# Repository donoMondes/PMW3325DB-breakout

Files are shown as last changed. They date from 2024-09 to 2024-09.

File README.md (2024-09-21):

# PMW3325DB-TWV1 breakout board

This repository contains PCB design files for a breakout board for the PMW3325DB optical mouse sensor.

The board doesn't do any level shifting so it only works with 3.3V logic.

The dimensions of the board are 45x25mm and the mounting holes are for M2 screws with meta inserts.

The files in the [fabrication](fabrication) folder can be used to order this board from JLCPCB with SMT assembly. The board you get includes everything except the actual sensor. If some of the specific components are out of stock, try to find an equivalent with the same package and parameters.

If the volatage regulator **TCR2EF19** is out of stock, you can replace it by using the following configuration :

| **Reference** | **Part Name** | **JLCPCB P/N** |**Description**|
|--- |--- |--- |---|
| U2 | TLV74318PDBVR | C15849 | Voltage regulator with Vout = 1.8v  |
| C1 | C15849 CL10A105KB8NNNC| C485152 | Capacitor of 1uF  |

**Warning** Don't forget to turn the TLV74318PDBVR when making the position during the PCBA process

The sensor chip should be soldered on the top side (the side where all the other components are). The dot marks pin 1. The optic goes on the bottom side.

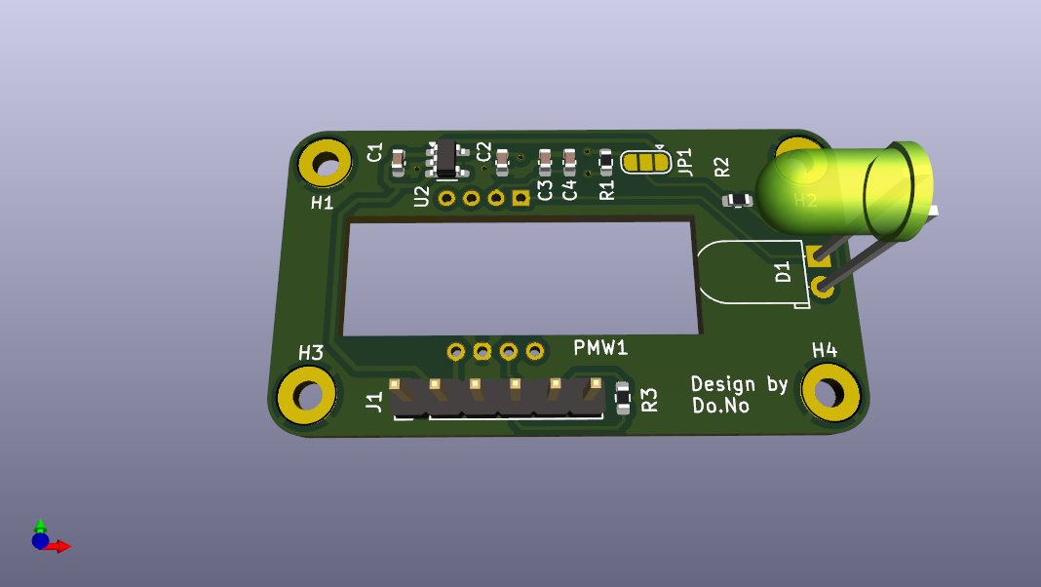
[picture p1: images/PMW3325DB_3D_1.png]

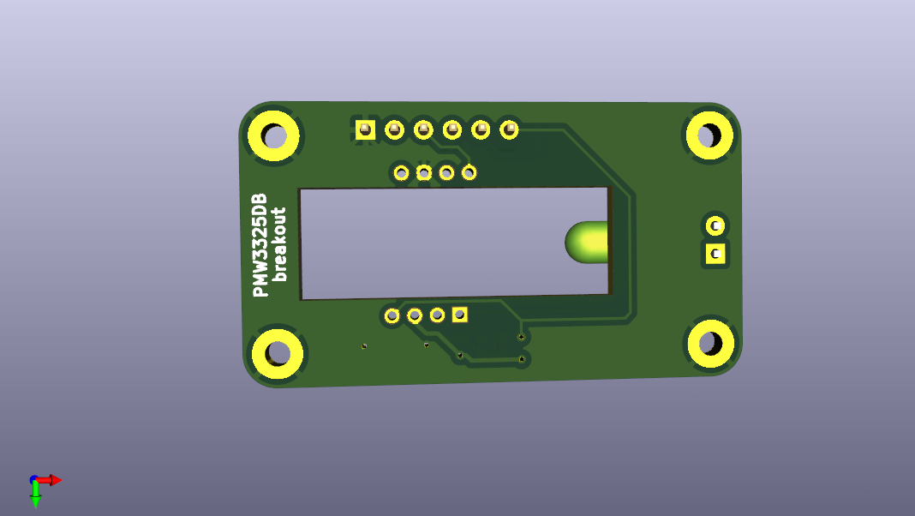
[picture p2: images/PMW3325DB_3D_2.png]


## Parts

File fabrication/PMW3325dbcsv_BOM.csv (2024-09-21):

Reference | Value | Datasheet | Footprint | Qty | DNP
C1 | 0.1u | ~ | Capacitor_SMD:C_0603_1608Metric | 1
C2 | 1u | ~ | Capacitor_SMD:C_0603_1608Metric | 1
C3 | 4.7u | ~ | Capacitor_SMD:C_0603_1608Metric | 1
C4 | 100nf | ~ | Capacitor_SMD:C_0603_1608Metric | 1
D1 | IR204A | http://www.everlight.com/file/ProductFile/IR204-A.pdf | LED_THT:LED_D5.0mm_Horizontal_O1.27mm_Z15.0mm | 1
J1 | Conn_01x06 | ~ | Connector _PINHeader:PinHeader_1x06_P2.54mm_Vertical | 1
PMW1 | PMW3325DB-TWV1 |  | adns 5050:PMW3325DB-TWV1 | 1
R1 | 10k | ~ | Resistor_SMD:R_0603_1608Metric | 1
R2 | 82 | ~ | Resistor_SMD:R_0603_1608Metric | 1
R3 | 3.3k | ~ | Resistor_SMD:R_0603_1608Metric | 1
U2 | TCR2EF19 |  | Package_TO_SOT_SMD:SOT-23-5 | 1

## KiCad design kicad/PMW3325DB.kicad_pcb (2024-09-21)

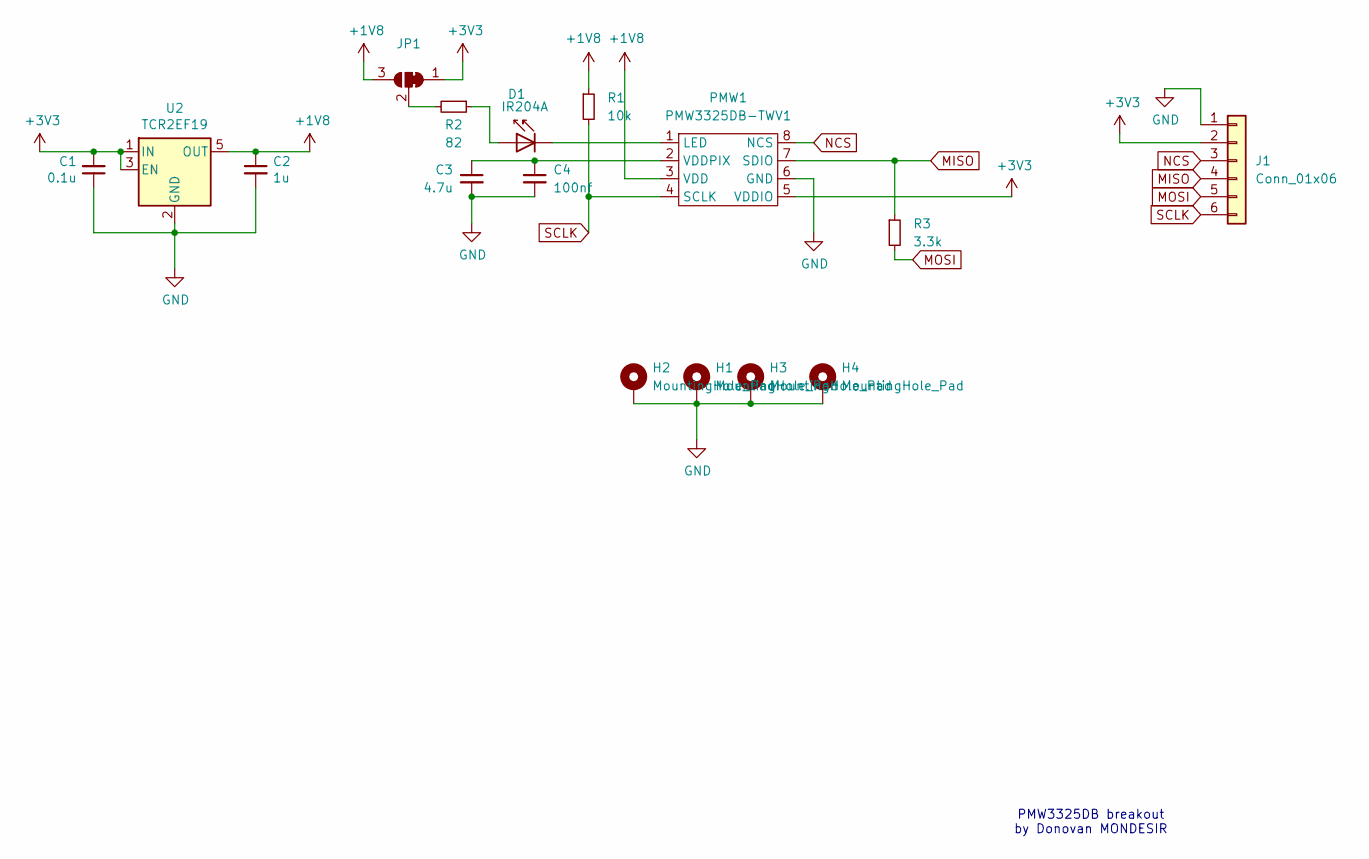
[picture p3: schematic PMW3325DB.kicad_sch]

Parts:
C1: 0.1u; C_0603_1608Metric; LCSC C14663
C2: 1u; C_0603_1608Metric; LCSC C15849
C3: 4.7u; C_0603_1608Metric; LCSC C19666
C4: 100nf; C_0603_1608Metric; LCSC C19666
D1: IR204A; LED_D5.0mm_Horizontal_O1.27mm_Z15.0mm
H1, H2, H3, H4: MountingHole_Pad; MountingHole_2.2mm_M2_Pad
J1: Conn_01x06; PinHeader_1x06_P2.54mm_Vertical
JP1: SolderJumper-3_P1.3mm_Bridged12_RoundedPad1.0x1.5mm
PMW1: PMW3325DB-TWV1
R1: 10k; R_0603_1608Metric; LCSC C25804
R2: 82; R_0603_1608Metric; LCSC C25804
R3: 3.3k; R_0603_1608Metric; LCSC C25804
U2: TCR2EF19; SOT-23-5; LCSC C146366

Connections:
+1V8: C2.1, JP1.3 (B), PMW1.3 (VDD), R1.1, U2.5 (OUT)
+3V3: C1.2, J1.2, JP1.1 (A), PMW1.5 (VDDIO), U2.1 (IN), U2.3 (EN)
GND: C1.1, C2.2, C3.2, C4.2, H1.1, H2.1, H3.1, H4.1, J1.1, PMW1.6 (GND), U2.2 (GND)
MISO: J1.4, PMW1.7 (SDIO), R3.1
MOSI: J1.5, R3.2
NCS: J1.3, PMW1.8 (NCS)
unnamed: D1.2 (A), R2.1
unnamed: D1.1 (K), PMW1.1 (LED)
unnamed: JP1.2 (C), R2.2
unnamed: C3.1, C4.1, PMW1.2 (VDDPIX)
SCLK: J1.6, PMW1.4 (SCLK), R1.2

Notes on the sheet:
PMW3325DB breakout by Donovan MONDESIR

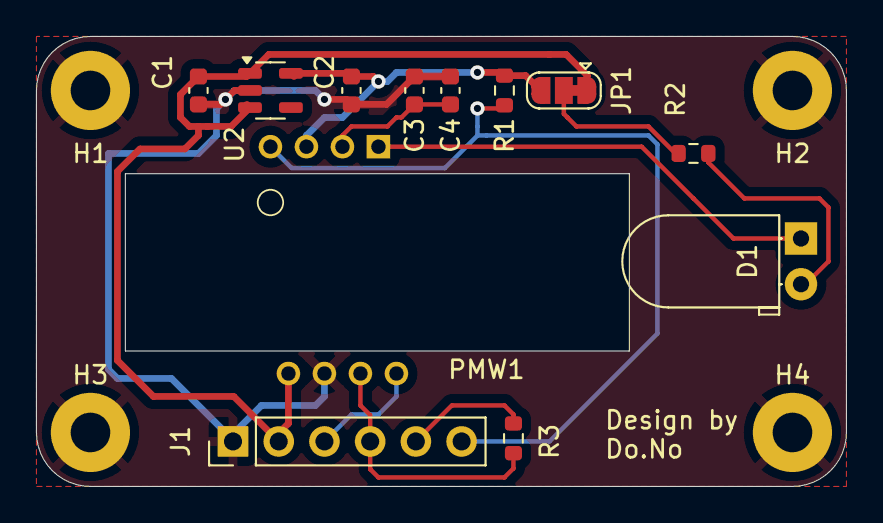
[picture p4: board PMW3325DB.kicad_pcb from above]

Board: 2 copper layers, 45.0 x 25.0 mm, 16 parts (0 on the bottom side), 11 nets.

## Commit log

2024-09-21 [fabrication] File needed for the fabrication process
    [PMW3325dbcsv_BOM.csv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]
2024-09-21 [kicad] kicad file for the pcb project
    [PMW3325DB-B_Cu.gbl, PMW3325DB-B_Mask.gbs, PMW3325DB-B_Paste.gbp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]
2024-09-21 [images] render of the pcb
